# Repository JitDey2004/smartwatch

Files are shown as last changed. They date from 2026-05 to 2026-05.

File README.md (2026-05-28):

# Open-Smartwatch GPS derivative - Modified by Jit Dey

This repository contains a modified derivative of the Open-Smartwatch GPS hardware project. The derivative work and local modifications are owned and maintained by Jit Dey.

The original hardware design, library references, and upstream project history remain credited to the Open-Smartwatch project. This folder keeps those references where they are required for attribution, license compliance, and KiCad compatibility.

This project preserves upstream Open-Smartwatch attribution and licensing while marking this folder as a modified derivative. See [NOTICE.md](NOTICE.md) for attribution details.

## Project Overview

This project is a KiCad-based hardware design for an ESP32 smartwatch-style GPS board. It includes the schematic, PCB layout, local symbol and footprint references, manufacturing gerbers, board plots, and supporting component documentation.

The design is intended as a compact wearable electronics board with support for a display, GPS module, microcontroller module, power management, USB interface, buttons, sensors, and storage-related circuitry. It can be used as a reference design for studying smartwatch hardware layout, modifying the circuit, or preparing a custom derivative board.

This version is maintained as a derivative by Jit Dey. The goal of this folder is to keep the project organized for further modification while preserving the original Open-Smartwatch source attribution.

## Project Contents

- KiCad schematic files: `osw.kicad_sch` `1759330689451.jfif` and legacy `osw.sch` `1759330713597.jfif`
- KiCad PCB layout: `osw.kicad_pcb` `1759330736489.jfif` `1759330746571.jfif`
- Local symbol and footprint library files under `lib/`
- Generated gerber files under `gerbers/`
- Board preview images and schematic documentation under `docs/`
- Interactive BOM and manufacturing support files
- GPL license and derivative attribution notice

Update 2025-06: There never was a release since the selected GPS module does not work on a wearable-sized PCB, and while worn at the same time.

## Current Status

This hardware project should be treated as a development/reference design, not a finished production-ready smartwatch. The GPS module choice and wearable-sized PCB constraints are known limitations from the upstream project notes. Anyone manufacturing or modifying the board should review the schematic, PCB layout, antenna/GPS behavior, power design, and component availability before ordering boards.

## Tools

## Schematic
Schematic

## Plots
front
bottom

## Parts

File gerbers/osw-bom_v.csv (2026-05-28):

Reference | Value | Package | Quantity | digikey_pn | mpn | manufacturer | digi-key_pn | manf | manf#
Unpolarized capacitor, small symbol | 10p | C_0603_1608Metric | 1
Unpolarized capacitor, small symbol | 100p | C_0603_1608Metric | 1
Unpolarized capacitor, small symbol | 0.1u | C_0603_1608Metric | 1
Unpolarized capacitor, small symbol | 0.1u | C_0603_1608Metric | 1
Unpolarized capacitor, small symbol | 0.1u | C_0603_1608Metric | 1
Unpolarized capacitor, small symbol | 0.1u | C_0603_1608Metric | 1
Unpolarized capacitor, small symbol | 0.1u | C_0603_1608Metric | 1
Unpolarized capacitor, small symbol | 0.1u | C_0603_1608Metric | 1
Unpolarized capacitor, small symbol | 0.1u | C_0603_1608Metric | 1
Unpolarized capacitor, small symbol | 0.1u | C_0603_1608Metric | 1
Unpolarized capacitor, small symbol | 0.1u | C_0603_1608Metric | 1
Unpolarized capacitor, small symbol | 0.1u | C_0603_1608Metric | 1
Unpolarized capacitor, small symbol | 0.1u | C_0603_1608Metric | 1
Unpolarized capacitor, small symbol | 0.1u | C_0603_1608Metric | 1
Unpolarized capacitor, small symbol | 0.1u | C_0603_1608Metric | 1
Unpolarized capacitor, small symbol | 0.1u | C_0603_1608Metric | 1
Unpolarized capacitor, small symbol | 4.7uF | C_0603_1608Metric | 1
Unpolarized capacitor, small symbol | 4.7u | C_0603_1608Metric | 1
Unpolarized capacitor, small symbol | 4.7u | C_0603_1608Metric | 1
Unpolarized capacitor, small symbol | 4.7uF | C_0603_1608Metric | 1
Unpolarized capacitor, small symbol | 100u | C_1206_3216Metric | 1
Unpolarized capacitor, small symbol | 100u | C_1206_3216Metric | 1
Light emitting diode, small symbol | LED_Green | LED_0805_2012Metric | 1
Generic connector, single row, 01x02, script generated (kicad-library-utils/schlib/autogen/connector/) | Conn_01x02 | PinHeader_1x02_P2.54mm_Vertical | 1
0.115A Id, 60V Vds, N-Channel MOSFET, SOT-23 | 2N7002 | SOT-23 | 1
Resistor, small symbol | 0R | R_0402_1005Metric | 1
Resistor, small symbol | 22 | R_0603_1608Metric | 1
Resistor, small symbol | 470R | R_0603_1608Metric | 1
Resistor, small symbol | 470R | R_0603_1608Metric | 1
Resistor, small symbol | 510R | R_0603_1608Metric | 1
Resistor, small symbol | 1k | R_0603_1608Metric | 1
Resistor, small symbol | 1k | R_0603_1608Metric | 1
Resistor, small symbol | 1k | R_0603_1608Metric | 1
Resistor, small symbol | 1k | R_0603_1608Metric | 1
Resistor, small symbol | 1k | R_0603_1608Metric | 1
Resistor, small symbol | 1k | R_0603_1608Metric | 1
Resistor, small symbol | 2.2K | R_0603_1608Metric | 1
Resistor, small symbol | 5k | R_0603_1608Metric | 1
Resistor, small symbol | 5.6k | R_0603_1608Metric | 1
Resistor, small symbol | 10k | R_0603_1608Metric | 1
Resistor, small symbol | 10k | R_0603_1608Metric | 1
Resistor, small symbol | 10k | R_0603_1608Metric | 1
Resistor, small symbol | 10k | R_0603_1608Metric | 1
Resistor, small symbol | 10k | R_0603_1608Metric | 1
Resistor, small symbol | 10k | R_0603_1608Metric | 1
Resistor, small symbol | 10k | R_0603_1608Metric | 1
Resistor, small symbol | 56k | R_0603_1608Metric | 1
Resistor, small symbol | 200k | R_0603_1608Metric | 1
Resistor, small symbol | 200k | R_0603_1608Metric | 1
Resistor, small symbol | 1M | R_0603_1608Metric | 1
Push button switch, generic, two pins | SW_Push | button_side_smd | 1
Push button switch, generic, two pins | SW_Push | button_side_smd | 1
Push button switch, generic, two pins | SW_Push | button_side_smd | 1
Push button switch, generic, two pins | SW_Push | button_side_smd | 1
 | BMA400 | LGA-12_2x2mm_P0.5mm | 1 | 828-1081-1-ND | BMA400 | Bosch Sensortec
 | CH340E | MSOP-10_3x3mm_P0.5mm | 1
±5ppm, I2C Real-Time Clock SOIC-8 | DS3231MZ | SOIC-8_3.9x4.9mm_P1.27mm | 1
 | GC9A01_IPS_display | GC9A01_IPS_display | 1
 | MCP73831T-2ACI_OT | SOT-23-5 | 1 |  | MCP73831T-2ACI/OT | Microchip Technology | MCP73831T-2ACI/OTCT-ND
 | PSRAM64H | SOP-8_3.9x4.9mm_P1.27mm | 1
 | Quectel_L96 | Quectel_L96 | 1
 | TPS2115A | TSSOP-8_4.4x3mm_P0.65mm | 1 | 296-16940-1-ND | TPS2115APWR | Texas Instruments
 | USB-OTG | USBmicro-B | 1
 | XC6209 | SOT-23-5 | 1
 | XC6209 | SOT-23-5 | 1
 | ttgo-32-micro | ttgo-32-micro | 1
 | SD_ebay-uSD-push_push_SMD | Conn_uSDcard | 1 |  |  |  |  | ebay | _

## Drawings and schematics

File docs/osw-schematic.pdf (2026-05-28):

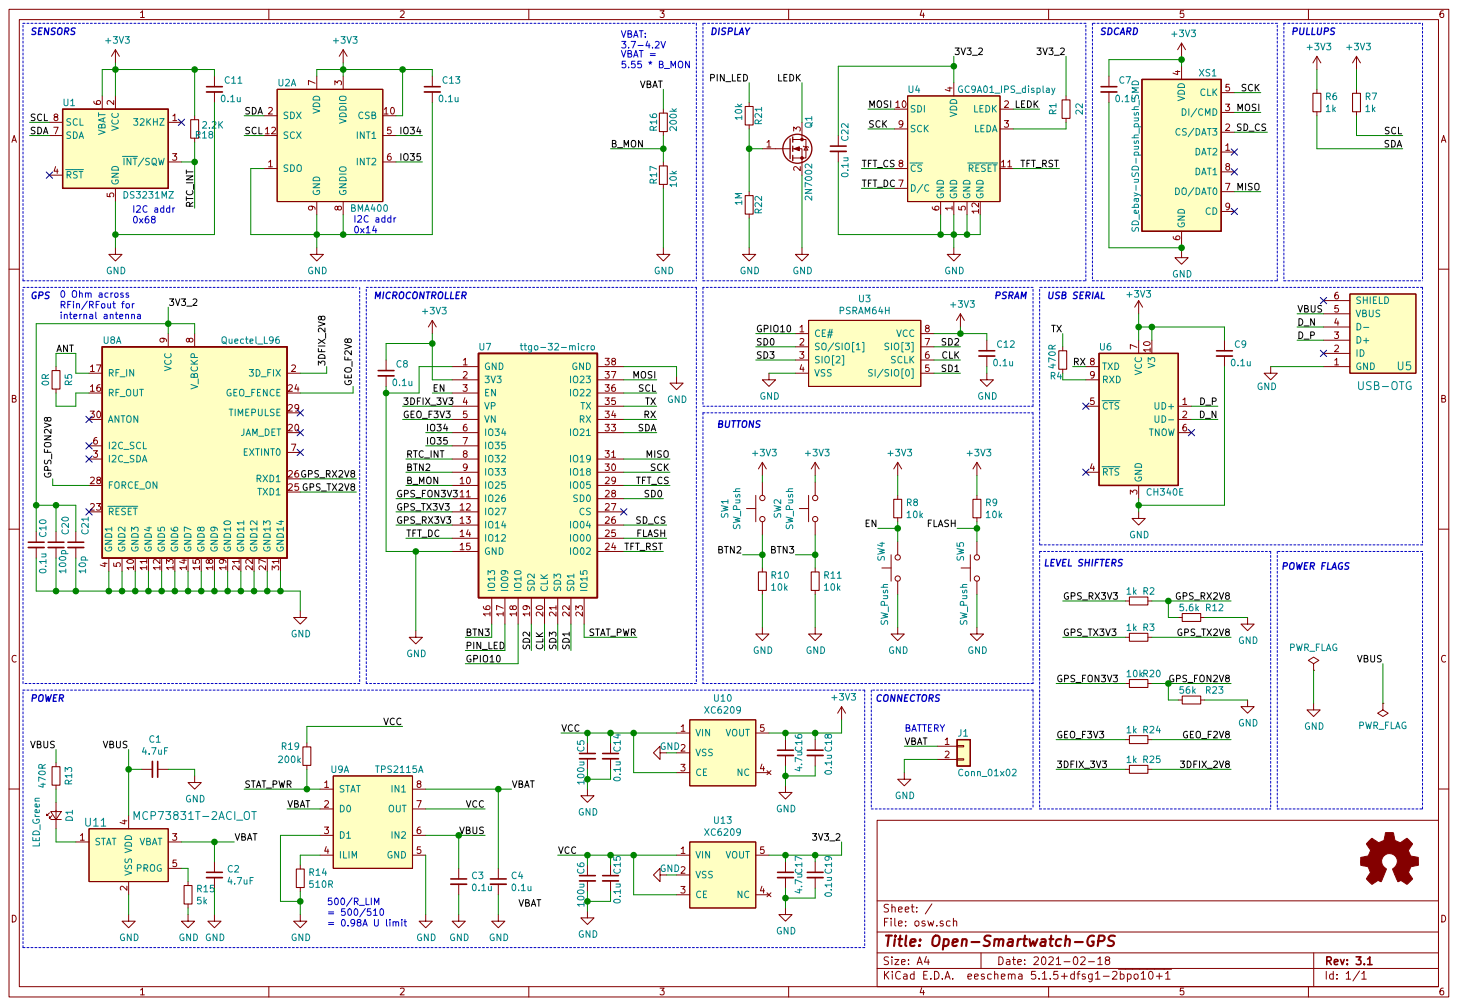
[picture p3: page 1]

6 DO/DAT0 7 DAT1 8 CD 9 XS1 SD_ebay-uSD-push_push_SMD R16 200k R17 10k GND
SCK RX MISO

6 SDA 7 SCL 8 U1 DS3231MZ GND 470R R13 EN GND

0 Ohm across RFin/RFout for

3 RTS 4 CTS 5 TNOW 6 VCC

Id: 1/1 Title: Open-Smartwatch-GPS

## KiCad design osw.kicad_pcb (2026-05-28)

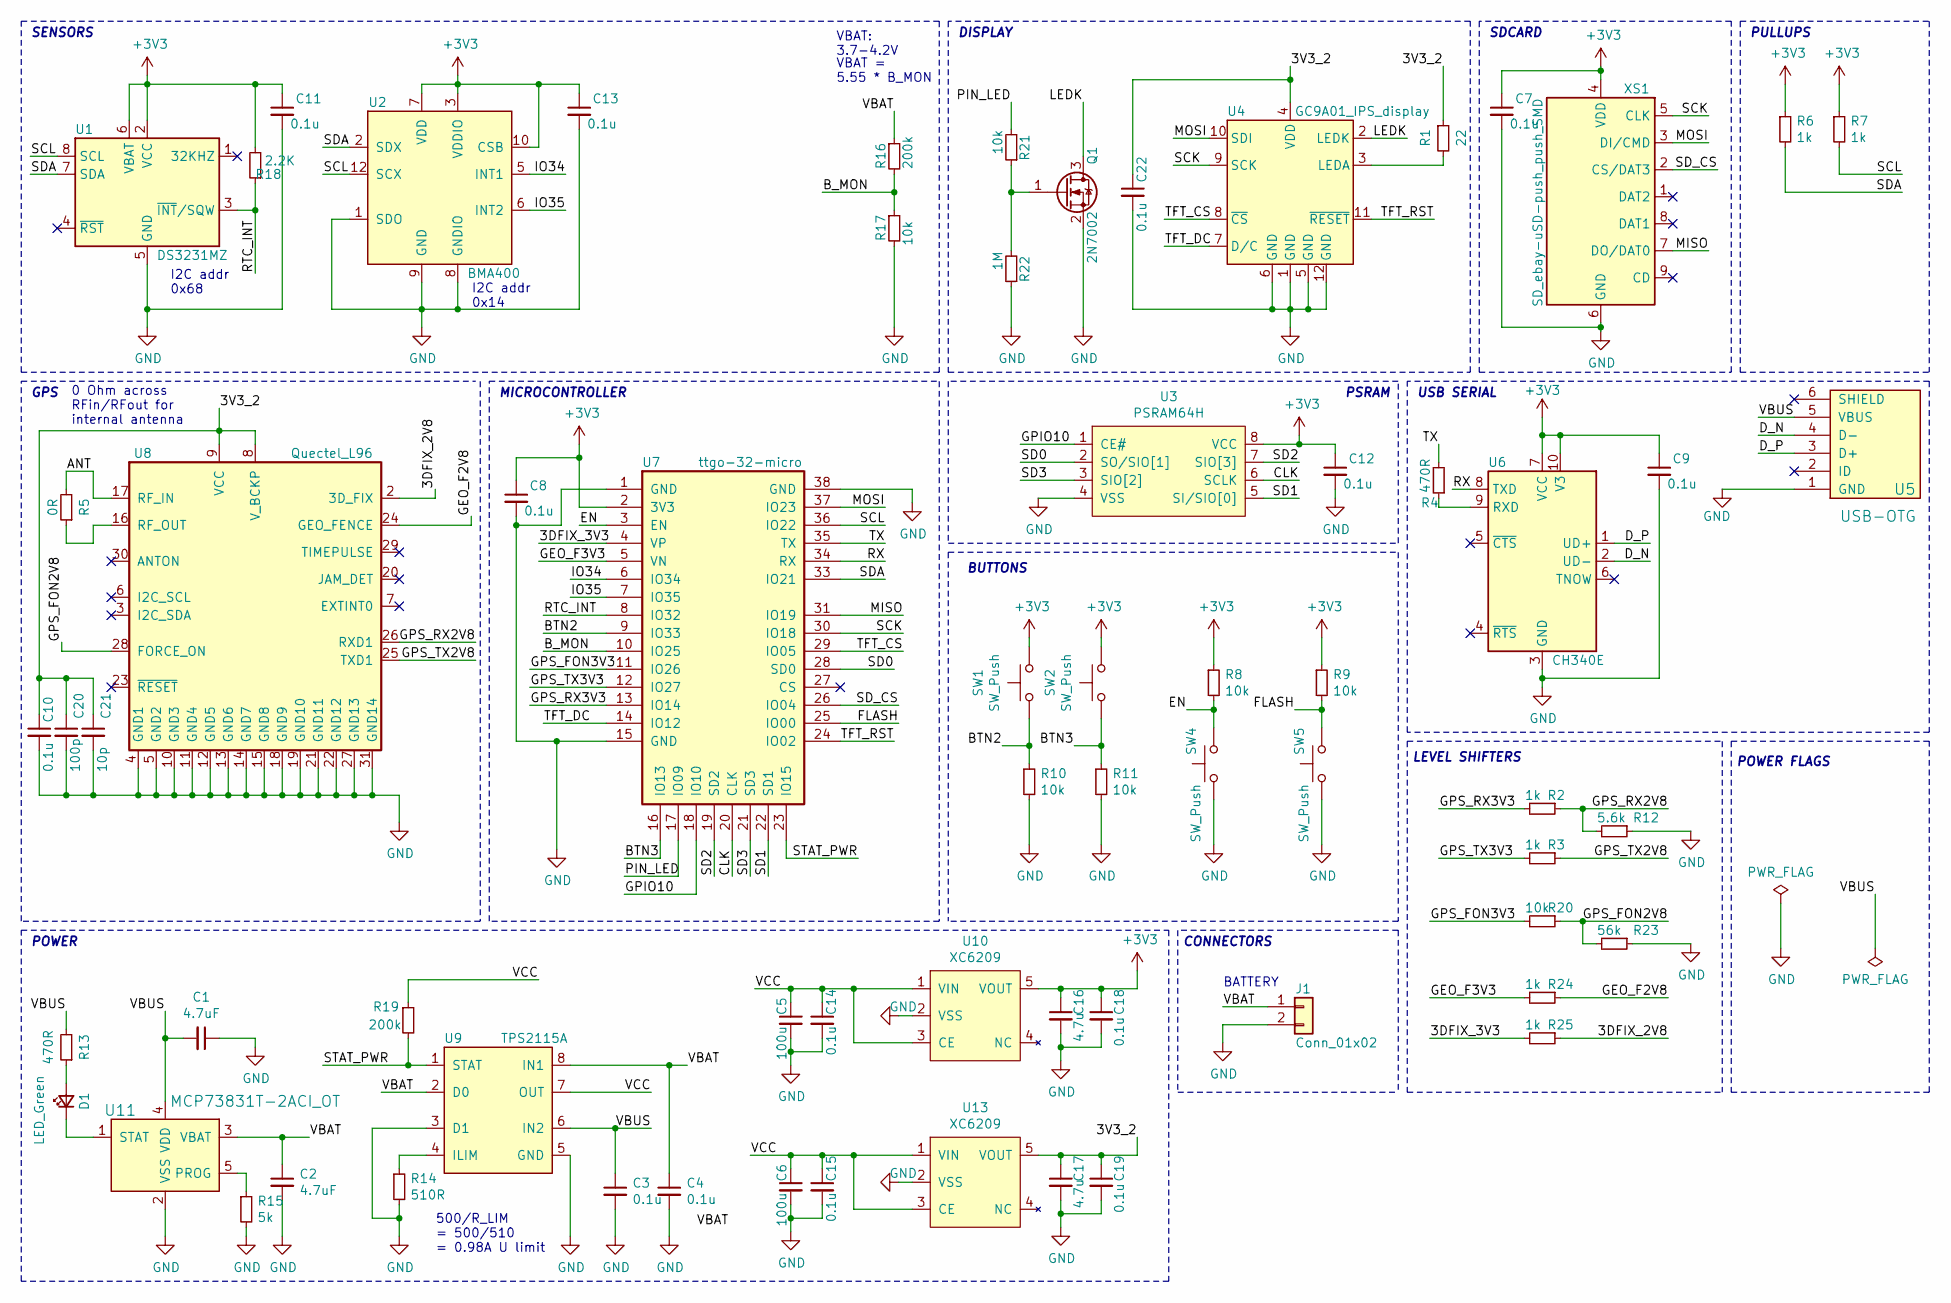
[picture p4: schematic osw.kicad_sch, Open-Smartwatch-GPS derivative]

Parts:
C1, C2: 4.7uF; C_0603_1608Metric
C3, C4, C7, C8, C9, C10, C11, C12, C13, C14, C15, C18, C19, C22: 0.1u; C_0603_1608Metric
C5, C6: 100u; C_1206_3216Metric
C16, C17: 4.7u; C_0603_1608Metric
C20: 100p; C_0603_1608Metric
C21: 10p; C_0603_1608Metric
D1: LED_Green; LED_0805_2012Metric
J1: Conn_01x02; PinHeader_1x02_P2.54mm_Vertical
Q1: 2N7002; SOT-23
R1: 22; R_0603_1608Metric
R2, R3, R6, R7, R24, R25: 1k; R_0603_1608Metric
R4, R13: 470R; R_0603_1608Metric
R5: 0R; R_0402_1005Metric
R8, R9, R10, R11, R17, R20, R21: 10k; R_0603_1608Metric
R12: 5.6k; R_0603_1608Metric
R14: 510R; R_0603_1608Metric
R15: 5k; R_0603_1608Metric
R16, R19: 200k; R_0603_1608Metric
R18: 2.2K; R_0603_1608Metric
R22: 1M; R_0603_1608Metric
R23: 56k; R_0603_1608Metric
SW1, SW2, SW4, SW5: SW_Push; button_side_smd
U1: DS3231MZ; SOIC-8_3.9x4.9mm_P1.27mm
U2: BMA400; LGA-12_2x2mm_P0.5mm; MPN BMA400; DigiKey_PN 828-1081-1-ND
U3: PSRAM64H; SOP-8_3.9x4.9mm_P1.27mm
U4: GC9A01_IPS_display
U5: USB-OTG; USBmicro-B
U6: CH340E; MSOP-10_3x3mm_P0.5mm
U7: ttgo-32-micro
U8: Quectel_L96
U9: TPS2115A; TSSOP-8_4.4x3mm_P0.65mm; MPN TPS2115APWR; DigiKey_PN 296-16940-1-ND
U10, U13: XC6209; SOT-23-5
U11: MCP73831T-2ACI_OT; SOT-23-5; MPN MCP73831T-2ACI/OT; Digi-Key_PN MCP73831T-2ACI/OTCT-ND
XS1: SD_ebay-uSD-push_push_SMD; Conn_uSDcard

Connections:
+3V3: C7.1, C8.1, C9.1, C11.1, C12.1, C13.1, C16.1, C18.1, R6.1, R7.1, R8.1, R9.1, R18.2, SW1.2, SW2.2, U1.2 (VCC), U1.6 (VBAT), U2.3 (VDDIO), U2.7 (VDD), U2.10 (CSB), U3.8 (VCC), U6.7 (VCC), U6.10 (V3), U7.2 (3V3), U10.5 (VOUT), XS1.4 (VDD)
/3DFIX_2V8: R25.1, U8.2 (3D_FIX)
/3DFIX_3V3: R25.2, U7.4 (VP)
/3V3_2: C10.1, C17.1, C19.1, C20.1, C21.1, C22.1, R1.1, U4.4 (VDD), U8.8 (V_BCKP), U8.9 (VCC), U13.5 (VOUT)
/ANT: R5.2, U8.17 (RF_IN)
/BTN2: R10.1, SW1.1, U7.9 (IO33)
/BTN3: R11.1, SW2.1, U7.16 (IO13)
/B_MON: R16.2, R17.1, U7.10 (IO25)
/CLK: U3.6 (SCLK), U7.20 (CLK)
/D_N: U5.4 (D-), U6.2 (UD-)
/D_P: U5.3 (D+), U6.1 (UD+)
/EN: R8.2, SW4.2, U7.3 (EN)
/FLASH: R9.2, SW5.2, U7.25 (IO00)
/GEO_F2V8: R24.1, U8.24 (GEO_FENCE)
/GEO_F3V3: R24.2, U7.5 (VN)
/GPIO10: U3.1 (CE#), U7.18 (IO10)
/GPS_FON2V8: R20.1, R23.2, U8.28 (FORCE_ON)
/GPS_FON3V3: R20.2, U7.11 (IO26)
/GPS_RX2V8: R2.1, R12.2, U8.26 (RXD1)
/GPS_RX3V3: R2.2, U7.13 (IO14)
/GPS_TX2V8: R3.1, U8.25 (TXD1)
/GPS_TX3V3: R3.2, U7.12 (IO27)
/IO34: U2.5 (INT1), U7.6 (IO34)
/IO35: U2.6 (INT2), U7.7 (IO35)
/LEDK: Q1.3 (D), U4.2 (LEDK)
/MISO: U7.31 (IO19), XS1.7 (DO/DAT0)
/MOSI: U4.10 (SDI), U7.37 (IO23), XS1.3 (DI/CMD)
/PIN_LED: R21.2, U7.17 (IO09)
/RTC_INT: R18.1, U1.3 (~INT/SQW), U7.8 (IO32)
/RX: U6.8 (TXD), U7.34 (RX)
/SCK: U4.9 (SCK), U7.30 (IO18), XS1.5 (CLK)
/SCL: R7.2, U1.8 (SCL), U2.12 (SCX), U7.36 (IO22)
/SD0: U3.2 (SO/SIO[1]), U7.28 (SD0)
/SD1: U3.5 (SI/SIO[0]), U7.22 (SD1)
/SD2: U3.7 (SIO[3]), U7.19 (SD2)
/SD3: U3.3 (SIO[2]), U7.21 (SD3)
/SDA: R6.2, U1.7 (SDA), U2.2 (SDX), U7.33 (IO21)
/SD_CS: U7.26 (IO04), XS1.2 (CS/DAT3)
/STAT_PWR: R19.2, U7.23 (IO15), U9.1 (STAT)
/TFT_CS: U4.8 (~CS), U7.29 (IO05)
/TFT_DC: U4.7 (D/C), U7.14 (IO12)
/TFT_RST: U4.11 (~RESET), U7.24 (IO02)
/TX: R4.2, U7.35 (TX)
/VBAT: C2.1, C4.1, J1.1, R16.1, U9.2 (D0), U9.8 (IN1), U11.3 (VBAT)
/VBUS: C1.2, C3.1, R13.2, U5.5 (VBUS), U9.6 (IN2), U11.4 (VDD)
/VCC: C5.1, C6.1, C14.1, C15.1, R19.1, U9.7 (OUT), U10.1 (VIN), U10.3 (CE), U13.1 (VIN), U13.3 (CE)
GND: C1.1, C2.2, C3.2, C4.2, C5.2, C6.2, C7.2, C8.2, C9.2, C10.2, C11.2, C12.2, C13.2, C14.2, C15.2, C16.2, C17.2, C18.2, C19.2, C20.2, C21.2, C22.2, J1.2, Q1.2 (S), R10.2, R11.2, R12.1, R14.2, R15.2, R17.2, R22.1, R23.1, SW4.1, SW5.1, U1.5 (GND), U2.1 (SDO), U2.8 (GNDIO), U2.9 (GND), U3.4 (VSS), U4.1 (GND), U4.5 (GND), U4.6 (GND), U4.12 (GND), U5.1 (GND), U6.3 (GND), U7.1 (GND), U7.15 (GND), U7.38 (GND), U8.4 (GND1), U8.5 (GND2), U8.10 (GND3), U8.11 (GND4), U8.12 (GND5), U8.13 (GND6), U8.14 (GND7), U8.15 (GND8), U8.18 (GND9), U8.19 (GND10), U8.21 (GND11), U8.22 (GND12), U8.27 (GND13), U8.31 (GND14), U9.3 (D1), U9.5 (GND), U10.2 (VSS), U11.2 (VSS), U13.2 (VSS), XS1.6 (GND)
unnamed: D1.2 (A), R13.1
unnamed: D1.1 (K), U11.1 (STAT)
unnamed: Q1.1 (G), R21.1, R22.2
unnamed: R1.2, U4.3 (LEDA)
unnamed: R4.1, U6.9 (RXD)
unnamed: R5.1, U8.16 (RF_OUT)
unnamed: R14.1, U9.4 (ILIM)
unnamed: R15.1, U11.5 (PROG)

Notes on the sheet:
LEVEL SHIFTERS
SENSORS
500/R_LIM = 500/510 = 0.98A U limit
0 Ohm across RFin/RFout for internal antenna
POWER FLAGS
VBAT = 5.55 * B_MON
POWER
CONNECTORS
PSRAM
I2C addr 0x14
GPS
PULLUPS
VBAT: 3.7-4.2V
SDCARD
MICROCONTROLLER
USB SERIAL
I2C addr 0x68
BATTERY
DISPLAY
BUTTONS

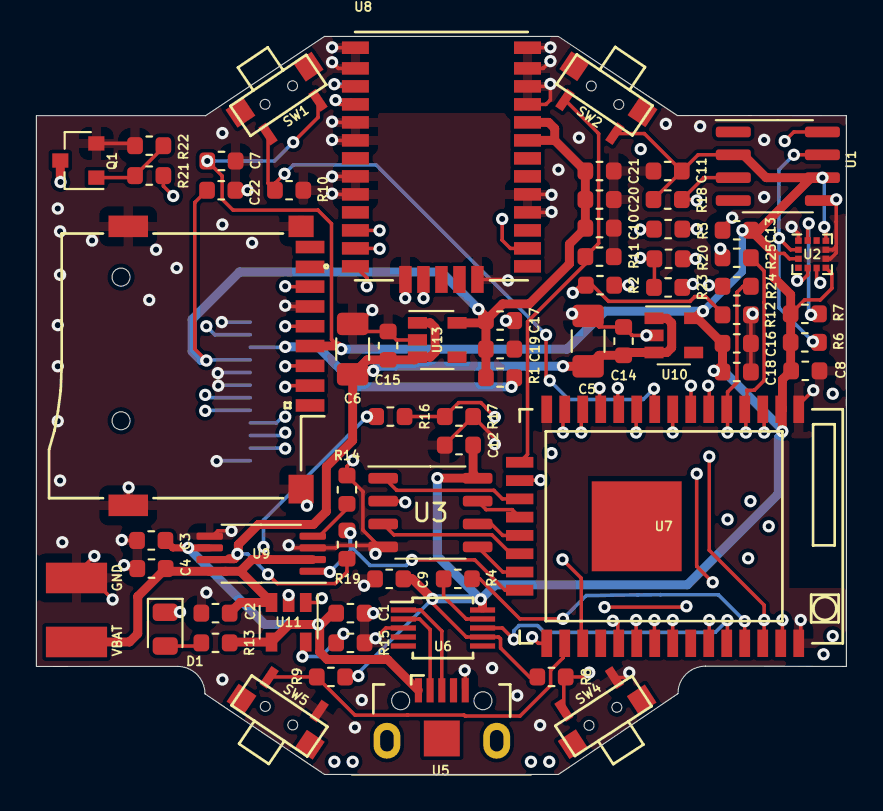
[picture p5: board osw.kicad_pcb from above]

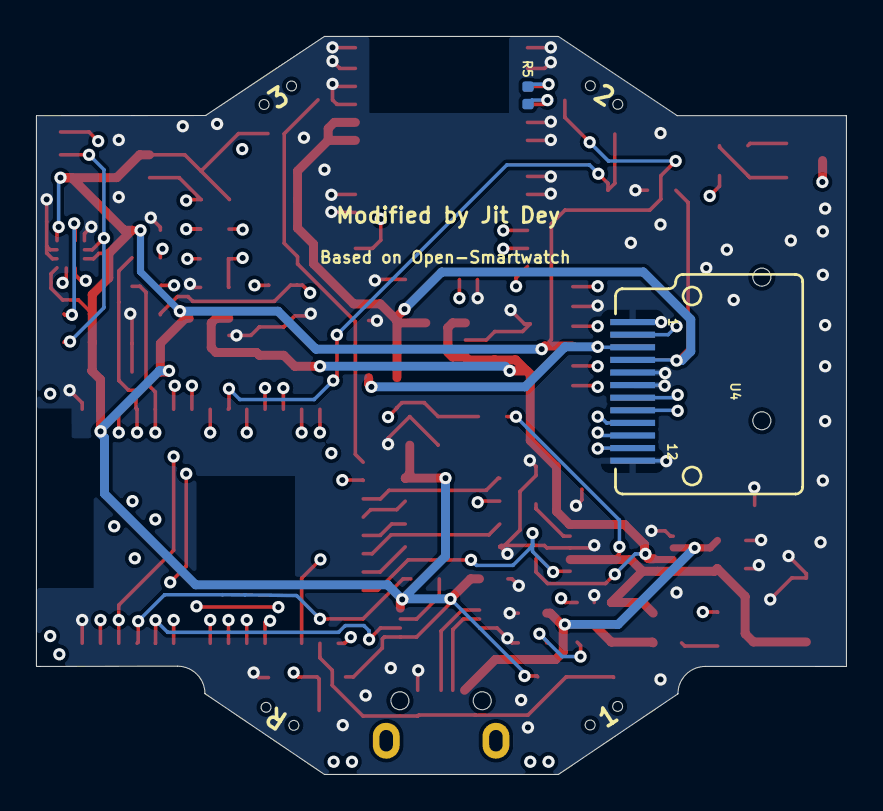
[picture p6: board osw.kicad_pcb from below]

Board: 4 copper layers, 45.0 x 41.0 mm, 67 parts (2 on the bottom side), 55 nets.
